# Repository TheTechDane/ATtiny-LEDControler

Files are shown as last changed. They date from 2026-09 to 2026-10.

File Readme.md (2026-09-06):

# ATtiny412 WS2812B Multi-Function LED Controller

A memory-optimized, bare-metal firmware for the **ATtiny412** microcontroller to drive up to **180 WS2812B / NeoPixel LEDs** using a single multi-function pushbutton. 

Designed for ultra-low SRAM environments (256 bytes total), the firmware utilizes **virtual tiling** and custom bit-bang streaming to repeat a 20-pixel pattern block across the full strip without running out of RAM.

All user settings (color, effect, and brightness) are bit-packed into a single byte and saved to EEPROM using a 10-second deferred write delay to maximize chip lifespan.

---

## Features

- **Virtual Tiling (180 LEDs on 256B RAM):** Allocates a 60-byte SRAM buffer (20 virtual pixels) and streams it 9 times continuously down the data wire without triggering a WS2812 reset latch.
- **Single Click:** Cycle through 8 preset colors (*Red, Yellow, Green, Cyan, Blue, Magenta, White, Warm White*).
- **Double Click:** Cycle through 8 animation modes:
  0. **Solid Color**
  1. **20-Pixel Chase**
  2. **10-Pixel Spaced Chase**
  3. **Breathing Pulse**
  4. **Alternating Blink**
  5. **Full Strip Blink**
  6. **Rainbow Spectrum Shift**
  7. **Smooth White Sparkle Fade** (Fades random LEDs smoothly to pure White at master strip brightness)
- **Long Press:** Smoothly ramps brightness in 5% steps (1% to 100%, alternating direction). Default startup brightness set to **50%** for power safety.
- **Smart EEPROM Save:** Bit-packs color, effect, and brightness into **1 byte** and commits after 10 seconds of button inactivity to prevent EEPROM wear.

***Optional***
- **Status LED:** Visual feedback for button presses on Pin 4 (`PA1`).
- **Serial Debugging:** Transmits telemetry at 115200 baud on Pin 2 (`PA6`) via `#define ENABLE_SERIAL`.

---

## Circuit Schematic & Connections

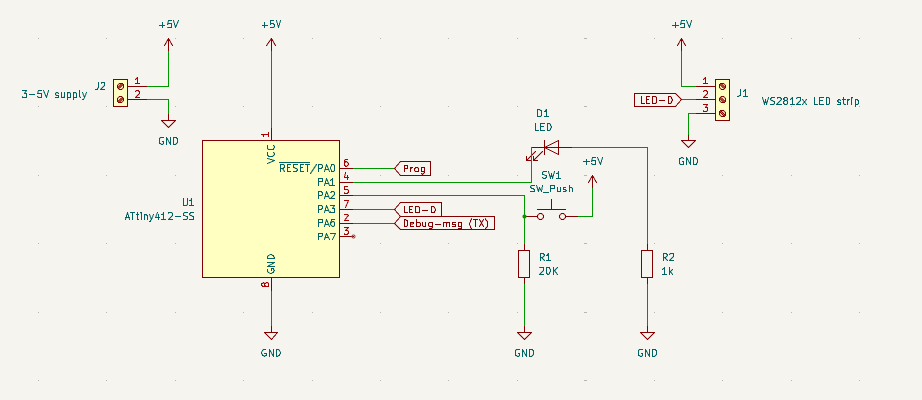
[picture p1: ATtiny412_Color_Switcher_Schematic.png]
ATtiny412 Schematic Diagram


### Hardware Pinout

| Physical Pin | AVR Pin | Function | Wiring Details |
| :---: | :---: | :--- | :--- |
| **1** | `VCC` | Power Supply | Connected to **+5V DC Power Rail** |
| **2** | `PA6` | (Serial TX) | ***Optional*** Debug output to USB-Serial Adapter RX |
| **3** | `PA7` | Unused | *Unconnected* |
| **4** | `PA1` | (Status LED) | ***Optional*** Anode (+) to Pin 4, Cathode (-) via 1kΩ Resistor to GND |
| **5** | `PA2` | Pushbutton | Button Pin 1 to **+5V**; Button Pin 2 to Pin 5 & **20kΩ Pull-down Resistor** to GND |
| **6** | `PA0` | UPDI | UPDI Programming Header |
| **7** | `PA3` | WS2812B Data | Connected directly to `DIN` on LED strip |
| **8** | `GND` | Ground | Connected to **Common Ground Rail (GND)** |

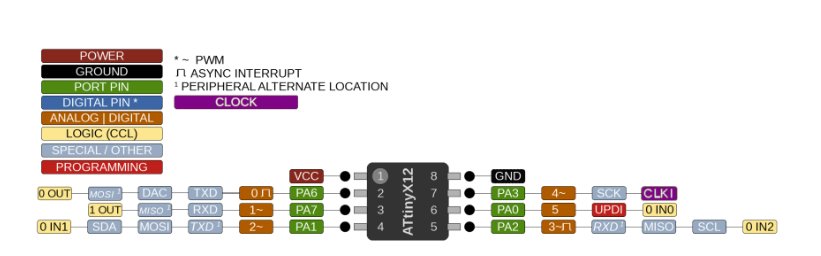
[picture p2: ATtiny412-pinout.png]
ATtiny412 Pinout


---

## Hardware Requirements

1. **ATtiny412** Microcontroller (SOIC-8 package)
2. **WS2812B LED Strip** (Up to 180 LEDs, powered by external +5V DC)
3. **1× Momentary Pushbutton**
4. **1× 20kΩ Resistor** (External pull-down for button)

***Optional***

5. **1× 1kΩ Resistor** (Current limiting for Status LED)
6. **1× Standard LED** (Status indicator)

---

## Build & Flash Instructions

1. Open `attiny412_LEDStrip_Ctrl.ino` in the **Arduino IDE**.
2. Install **megaTinyCore** via the Arduino Board Manager.
3. Configure target board settings:
   - **Board:** ATtiny412 / 402 / 212 / 202
   - **Clock:** 16 MHz or 20 MHz internal

***Optional***

4. **Upload Firmware:** Upload the compiled binary using a **SerialUPDI** or **jtag2updi** programmer connected to Pin 6 (`PA0`).
5. **Enable/Disable Serial Debugging:** Line 23 of the sketch contains `#define ENABLE_SERIAL`. Keep this line active to stream telemetry at 115200 baud on Pin 2 (`PA6`). Comment it out (`// #define ENABLE_SERIAL`) to disable debug output, save Flash memory, and reduce execution overhead.

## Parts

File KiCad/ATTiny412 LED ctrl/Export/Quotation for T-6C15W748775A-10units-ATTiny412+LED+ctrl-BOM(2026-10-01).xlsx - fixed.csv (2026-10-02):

PCBWay Bom Quotation, Product No.:T-6C15W748775A
Item # | *Designator | *Qty | Manufacturer | *Mfg Part # | Description / Value | *Package/Footprint | Mounting Type | Your Instructions / Notes | *Unit Price(10 units) | *Total | *Delivery Time | *PCBWay Note | Customer Reply | PCBWay Update
1 | D1 | 1 | Wurth Elektronik | 151033RS03000 | LED | T-1 (3 mm)『 』LED_D3.0mm_Clear | PTH | 1『 』https://www.mouser.dk/ |  |  |  | [It's out of stock. Please recommend substitutes or you can supply this part to us.] | FIXED
2 | J1 | 1 |  | No mount | WS2812x LED strip | TerminalBlock_MaiXu_MX126-5.0-03P_1x03_P5.00mm | PTH | 1 |  |  |  | [DNP];we won't purchase or populate it
3 | J2 | 1 |  | No mount | 3-5V supply | TerminalBlock_MaiXu_MX126-5.0-02P_1x02_P5.00mm | PTH | 1 |  |  |  | [DNP];we won't purchase or populate it
4 | R1 (sw) | 1 | Royalohm | CFR0W8J0203A20 | 20K | 3.6 mm『 』R_Axial_DIN0204_L3.6mm_D1.6mm_P7.62mm_Horizontal | PTH | 1『 』https://www.mouser.dk/ | $0,095 | $0,950 |  | The correct resistance value for the listed Part Number [CFR0W8J0824A20] is indeed [820kΩ], not [20KΩ]. | FIXED
5 | R2 (led) | 1 | Royalohm | CFR0W8J0102A20 | 1k | 3.6 mm『 』R_Axial_DIN0204_L3.6mm_D1.6mm_P7.62mm_Horizontal | PTH | 1『 』https://www.mouser.dk/ | $0,095 | $0,950
6 | SW1 | 1 | C&K Switches | PTS647SN70SMTR2N LFS | SW_Push | Gull Wing Lead『 』SW_SPST_PTS647_Sx38 | SMD | 1『 』https://www.mouser.dk/ | $0,442 | $4,420 | 7-10 Workdays
7 | U1 | 1 | Microchip | ATTINY412-SSN | ATtiny412-SS | SOIC-8『 』SOIC-8_3.9x4.9mm_P1.27mm | SMD | 1『 』https://www.mouser.dk/ | $0,773 | $7,730 | 7-10 Workdays
 |  |  |  |  |  |  |  |  | Component Cost | $14,05 | incomplete
 |  |  |  |  |  |  |  |  | Assembly Cost | $29,00
 |  |  |  |  |  |  |  |  | PCB Cost | $17,65
 |  |  |  |  |  |  |  |  | V1 Member 1% off | -$0,47
 |  |  |  |  |  |  |  |  | All Total 10 Units | $60,23

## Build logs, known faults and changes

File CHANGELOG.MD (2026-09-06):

# Changelog

All notable changes to the ATtiny412 WS2812B Multi-Function LED Controller will be documented in this file.

The format is based on [Keep a Changelog](https://keepachangelog.com/en/1.0.0/),
and this project adheres to [Semantic Versioning](https://semver.org/spec/v2.0.0.html).

---

## [1.2.0] - 2026-09-06

### 🚀 Added
- **10-Pixel Spaced Chase (Effect 2):** Added a denser dual-chase pattern running two active pixels spaced 10 LEDs apart across the 20-pixel virtual block.
- **Rainbow Spectrum Shift (Effect 6):** Integrated a compact 256-hue spectrum shift algorithm moving smoothly across virtual tiles.
- **Smooth White Sparkle Fade (Effect 7):** Re-engineered the Sparkle effect to smoothly ramp random individual LEDs to pure White at master strip brightness and fade them back down across a 1-second interval.
- **Fast PRNG (`fastRandom`):** Added a lightweight 16-bit Linear Feedback Shift Register pseudo-random number generator to replace bulky standard library `rand()` calls.

### ⚡ Optimizations & Memory Engineering
- **180-LED Bare-Metal Virtual Tiling Streamer (`sendRawBytesTiled`):** Bypassed standard library reset delays with custom PORTA bit-bang streaming. Transmits a 60-byte SRAM buffer (20 virtual pixels) 9 times continuously down the data wire without triggering mid-stream WS2812 reset pulses.
- **Power Rail Safety:** Adjusted default initial startup brightness to **50%** (`brightnessStep = 10`) to prevent current spikes and programmer brownouts during USB/UPDI testing.

### 🛠️ Fixed
- **Button Double-Click State Machine:** Overhauled `handleButton()` state tracking with decoupled click-window logic (`DBL_CLICK_MS = 280ms`), eliminating click drops during heavy animation rendering passes.
- **Strict SRAM Allocation:** Guaranteed total SRAM usage stays under 60 bytes (for LED buffers), leaving plenty of headspace in the ATtiny412's 256-byte SRAM pool.

---

## [1.1.0] - 2026-09-06

### 🚀 Added
- Expanded effect library to 5 modes (Solid, Moving Chase, Breathing Pulse, Alternating Blink, Full Blink).
- Multi-click button interaction framework (Single Click: Color, Double Click: Effect, Long Press: Brightness).

### ⚡ Optimizations
- **Smart EEPROM Save:** Bit-packed color, effect, and brightness settings into a single 8-bit byte with a 10-second deferred write delay to reduce EEPROM wear.

---

## [1.0.0] - 2026-08-20

### 🚀 Initial Release
- Basic WS2812B controller implementation for ATtiny412 microcontroller.
- Single button input with debouncing.
- Optional Serial debugging output at 115200 baud on Pin 2 (`PA6`).

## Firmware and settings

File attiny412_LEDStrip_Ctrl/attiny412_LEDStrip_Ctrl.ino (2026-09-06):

/*
 * ATtiny412 WS2812B Multi-Function Controller (Smooth White Fade Sparkle)
 * -----------------------------------------------------------------------------
 * LED CAPACITY CONSTRAINTS:
 * - RAM Limit: ATtiny412 has 256 bytes of SRAM total.
 * - Strip Size: Drives up to 180 physical LEDs.
 * - Pattern Buffer: Allocates RAM for 20 pixels (60 bytes SRAM) and streams 
 *   it 9 times continuously using low-level bit-banging.
 * 
 * INTERACTION:
 * - Single Click: Cycle Color (8 Presets including Warm White)
 * - Double Click: Cycle Effects (0: Solid, 1: 20px Chase, 2: 10px Chase, 
 *                 3: Breathe, 4: Alt Blink, 5: Full Blink, 6: Rainbow, 7: Sparkle Fade)
 * - Long Press:   Adjust Brightness (5% steps, 1% to 100%, alternating direction)
 * - EEPROM:       Bit-packed (1 byte) with 10-second deferred write delay.
 */

#include <EEPROM.h>

// =============================================================================
// COMPILER FLAGS & CONFIGURATION
// =============================================================================
#define ENABLE_SERIAL // Active Serial debugging on PA6

#define VIRTUAL_LEDS  20   // Pattern resolution in RAM (60 bytes SRAM)
#define ACTUAL_LEDS   180  // Total physical LEDs on strip (180 / 20 = 9 repeats)
#define NUM_REPEAT    (ACTUAL_LEDS / VIRTUAL_LEDS)
#define NUM_EFFECTS   8    // Total animation modes (0 to 7)

// EEPROM Config
#define EEPROM_ADDR_DATA      0
#define EEPROM_SAVE_DELAY_MS  10000 // 10-second delay after last button interaction

// Hardware Pin Definitions
#define LED_PIN       PIN_PA1  // Physical Pin 4 (Status LED)
#define BUTTON_PIN    PIN_PA2  // Physical Pin 5 (Button)
#define LEDSTRIP_PIN  PIN_PA3  // Physical Pin 7 (WS2812B Data Line - Bit 3 on PORTA)
#define DATA_BIT      3        // PA3

// Button Timing Constraints (ms)
#define DEBOUNCE_MS     40
#define DBL_CLICK_MS   280
#define LONG_PRESS_MS  500

// Memory buffer allocated strictly for 20 virtual pixels (60 bytes SRAM, GRB layout)
uint8_t pixels[VIRTUAL_LEDS * 3];

uint8_t colorIndex = 0;          // Range: 0 to 7
uint8_t currentEffect = 0;       // Range: 0 to 7
uint8_t brightnessStep = 10;     // Range: 0 to 20 (Set to 10 = 50% default brightness)
int8_t brightnessDirection = -1; // Ramps DOWN on first hold

// EEPROM Deferral State Variables
bool eepromDirty = false;
unsigned long lastSettingChangeTime = 0;

// Fast Lightweight PRNG state
uint16_t rngState = 0xACE1;

// Colors stored in FLASH (PROGMEM)
const uint8_t colors[8][3] PROGMEM = {
  {255, 0,   0  }, // Red
  {255, 255, 0  }, // Yellow
  {0,   255, 0  }, // Green
  {0,   255, 255}, // Cyan
  {0,   0,   255}, // Blue
  {255, 0,   255}, // Magenta
  {255, 255, 255}, // White
  {255, 197, 143}  // Warm White
};

// Button tracking variables
bool lastButtonState = LOW;
unsigned long buttonPressTime = 0;
unsigned long buttonReleaseTime = 0;
uint8_t clickCount = 0;
bool longPressExecuted = false;

// Effect animation states
unsigned long lastEffectUpdate = 0;
uint8_t effectStep = 0;
int8_t breatheDirection = 1;
uint8_t breatheStep = 100;
bool blinkToggleState = false;
uint8_t rainbowWheelPos = 0;

// Sparkle Fade state variables
uint8_t sparkleFadeProgress = 0;  // 0 to 100 (fade position inside cycle)
int8_t sparkleFadeDirection = 5;  // Step speed for fading in/out
uint8_t sparkleActivePixel = 0;   // Currently sparkling pixel index

// Lightweight 16-bit PRNG
uint16_t fastRandom() {
  rngState = (rngState >> 1) ^ (-(rngState & 1u) & 0xB400u);
  return rngState;
}

// -----------------------------------------------------------------------------
// HARDWARE WS2812B LOW-LEVEL BITBANG STREAMER
// -----------------------------------------------------------------------------
void sendRawBytesTiled(uint8_t *data, uint16_t length, uint8_t repeats) {
  uint8_t pinMask = (1 << DATA_BIT);
  
  noInterrupts();
  
  for (uint8_t r = 0; r < repeats; r++) {
    for (uint16_t i = 0; i < length; i++) {
      uint8_t b = data[i];
      for (int8_t bit = 7; bit >= 0; bit--) {
        if (b & (1 << bit)) {
          PORTA.OUTSET = pinMask;
          asm volatile("nop\n nop\n nop\n nop\n nop\n nop\n nop\n nop\n");
          PORTA.OUTCLR = pinMask;
          asm volatile("nop\n nop\n");
        } else {
          PORTA.OUTSET = pinMask;
          asm volatile("nop\n nop\n");
          PORTA.OUTCLR = pinMask;
          asm volatile("nop\n nop\n nop\n nop\n nop\n nop\n nop\n nop\n");
        }
      }
    }
  }
  
  interrupts();
  delayMicroseconds(60); // Force WS2812 Reset pulse
}

void setPixelGRB(uint8_t index, uint8_t r, uint8_t g, uint8_t b) {
  if (index >= VIRTUAL_LEDS) return;
  pixels[index * 3 + 0] = g; // Green
  pixels[index * 3 + 1] = r; // Red
  pixels[index * 3 + 2] = b; // Blue
}

// Compact Hue-to-RGB conversion
void getRainbowColor(uint8_t pos, uint8_t *r, uint8_t *g, uint8_t *b) {
  pos = 255 - pos;
  if (pos < 85) {
    *r = 255 - pos * 3; *g = 0; *b = pos * 3;
  } else if (pos < 170) {
    pos -= 85;
    *r = 0; *g = pos * 3; *b = 255 - pos * 3;
  } else {
    pos -= 170;
    *r = pos * 3; *g = 255 - pos * 3; *b = 0;
  }
}

// -----------------------------------------------------------------------------
// BIT-PACKING & EEPROM HELPERS
// -----------------------------------------------------------------------------
uint8_t packSettings() {
  uint8_t bScale = brightnessStep / 6; // Map 0-20 down to 0-3 (2 bits)
  return (colorIndex & 0x07) | ((currentEffect & 0x07) << 3) | ((bScale & 0x03) << 6);
}

void unpackSettings(uint8_t packedVal) {
  colorIndex = packedVal & 0x07;
  currentEffect = (packedVal >> 3) & 0x07;
  brightnessStep = ((packedVal >> 6) & 0x03) * 6;
  if (brightnessStep > 20) brightnessStep = 20;
}

void markSettingChanged() {
  eepromDirty = true;
  lastSettingChangeTime = millis();
}

void processEEPROMSave() {
  if (eepromDirty && (millis() - lastSettingChangeTime >= EEPROM_SAVE_DELAY_MS)) {
    EEPROM.update(EEPROM_ADDR_DATA, packSettings());
    eepromDirty = false;

#ifdef ENABLE_SERIAL
    Serial.println(F("Saved to EEPROM!"));
#endif
  }
}

void loadSettings() {
  uint8_t packedVal = EEPROM.read(EEPROM_ADDR_DATA);
  if (packedVal != 0xFF) {
    unpackSettings(packedVal);
    if (colorIndex >= 8) colorIndex = 0;
    if (currentEffect >= NUM_EFFECTS) currentEffect = 0;
  }
}

// -----------------------------------------------------------------------------
// LED OUTPUT CONTROLLER
// -----------------------------------------------------------------------------
void applyStripOutput() {
  uint8_t baseR = pgm_read_byte(&(colors[colorIndex][0]));
  uint8_t baseG = pgm_read_byte(&(colors[colorIndex][1]));
  uint8_t baseB = pgm_read_byte(&(colors[colorIndex][2]));

  uint8_t scaleFactor = (brightnessStep == 0) ? 3 : (uint8_t)((uint16_t)brightnessStep * 255 / 20);

  if (currentEffect == 3) { // Breathing Pulse
    scaleFactor = (scaleFactor * breatheStep) / 100;
  }

  uint8_t r = (baseR * scaleFactor) >> 8;
  uint8_t g = (baseG * scaleFactor) >> 8;
  uint8_t b = (baseB * scaleFactor) >> 8;

  // Populate 20-pixel Virtual Pattern Buffer
  for (uint8_t i = 0; i < VIRTUAL_LEDS; i++) {
    uint8_t pr = r, pg = g, pb = b;

    if (currentEffect == 1) { // 20-pixel Chase
      bool active = (i == (effectStep % VIRTUAL_LEDS));
      pr = active ? r : 0; pg = active ? g : 0; pb = active ? b : 0;
    } 
    else if (currentEffect == 2) { // 10-pixel Spaced Chase
      bool active = ((i % 10) == (effectStep % 10));
      pr = active ? r : 0; pg = active ? g : 0; pb = active ? b : 0;
    }
    else if (currentEffect >= 4 && currentEffect <= 5) { // Blink / Alt Blink
      bool active = (currentEffect == 5) ? blinkToggleState : ((i % 2 == 0) ? blinkToggleState : !blinkToggleState);
      pr = active ? r : 0; pg = active ? g : 0; pb = active ? b : 0;
    } 
    else if (currentEffect == 6) { // Rainbow Spectrum
      getRainbowColor((uint8_t)((i * 256 / VIRTUAL_LEDS) + rainbowWheelPos), &pr, &pg, &pb);
      pr = (pr * scaleFactor) >> 8;
      pg = (pg * scaleFactor) >> 8;
      pb = (pb * scaleFactor) >> 8;
    } 
    else if (currentEffect == 7) { // Smooth White Fade Sparkle
      if (i == sparkleActivePixel) {
        // Calculate cross-fade between base color and pure white based on fade progress
        uint8_t targetWhite = scaleFactor; // Matches exact current strip brightness
        pr = r + (((int16_t)targetWhite - r) * sparkleFadeProgress / 100);
        pg = g + (((int16_t)targetWhite - g) * sparkleFadeProgress / 100);
        pb = b + (((int16_t)targetWhite - b) * sparkleFadeProgress / 100);
      }
    }

    setPixelGRB(i, pr, pg, pb);
  }

  // Stream raw buffer 9 times (180 LEDs)
  sendRawBytesTiled(pixels, VIRTUAL_LEDS * 3, NUM_REPEAT);
}

// -----------------------------------------------------------------------------
// BUTTON INTERACTION HANDLERS
// -----------------------------------------------------------------------------
void onSingleClick() {
  digitalWrite(LED_PIN, HIGH);
  colorIndex = (colorIndex + 1) % 8;
  markSettingChanged();
  applyStripOutput();

#ifdef ENABLE_SERIAL
  Serial.print(F("Color: "));
  Serial.println(colorIndex);
#endif

  delay(20);
  digitalWrite(LED_PIN, LOW);
}

void onDoubleClick() {
  digitalWrite(LED_PIN, HIGH);
  currentEffect = (currentEffect + 1) % NUM_EFFECTS;
  markSettingChanged();
  applyStripOutput();

#ifdef ENABLE_SERIAL
  Serial.print(F("Effect: "));
  Serial.println(currentEffect);
#endif

  delay(100);
  digitalWrite(LED_PIN, LOW);
}

void onLongPressHold() {
  digitalWrite(LED_PIN, HIGH);

  int8_t nextStep = brightnessStep + brightnessDirection;

  if (nextStep >= 20) brightnessStep = 20;
  else if (nextStep <= 0) brightnessStep = 0;
  else brightnessStep = nextStep;

  applyStripOutput();

#ifdef ENABLE_SERIAL
  Serial.print(F("Bright: "));
  Serial.print(brightnessStep == 0 ? 1 : brightnessStep * 5);
  Serial.println(F("%"));
#endif

  delay(30);
  digitalWrite(LED_PIN, LOW);
}

void handleButton() {
  bool currentButtonState = digitalRead(BUTTON_PIN);
  unsigned long now = millis();

  if (currentButtonState == HIGH && lastButtonState == LOW) {
    buttonPressTime = now;
    longPressExecuted = false;
  }

  if (currentButtonState == HIGH && (now - buttonPressTime >= LONG_PRESS_MS)) {
    clickCount = 0;
    onLongPressHold();
    delay(80); 
    longPressExecuted = true;
  }

  if (currentButtonState == LOW && lastButtonState == HIGH) {
    buttonReleaseTime = now;

    if (longPressExecuted) {
      markSettingChanged();
      brightnessDirection = -brightnessDirection;
    } else if (now - buttonPressTime >= DEBOUNCE_MS) {
      clickCount++;
    }
  }

  if (clickCount > 0 && (now - buttonReleaseTime > DBL_CLICK_MS) && currentButtonState == LOW) {
    if (clickCount == 1) {
      onSingleClick();
    } else if (clickCount >= 2) {
      onDoubleClick();
    }
    clickCount = 0;
  }

  lastButtonState = currentButtonState;
}

// -----------------------------------------------------------------------------
// SETUP & MAIN LOOP
// -----------------------------------------------------------------------------
void setup() {
#ifdef ENABLE_SERIAL
  Serial.begin(115200, SERIAL_8N1 | SERIAL_TX_ONLY);
  Serial.println(F("Ready"));
#endif

  pinMode(LED_PIN, OUTPUT);
  pinMode(LEDSTRIP_PIN, OUTPUT);
  pinMode(BUTTON_PIN, INPUT);

  loadSettings();

  applyStripOutput();
}

void loop() {
  handleButton();
  processEEPROMSave();

  if (currentEffect > 0) {
    unsigned long now = millis();
    uint16_t interval = 80;

    if (currentEffect == 1 || currentEffect == 2) interval = 80;
    else if (currentEffect == 3) interval = 25;
    else if (currentEffect == 4) interval = 300;
    else if (currentEffect == 5) interval = 250;
    else if (currentEffect == 6) interval = 30; // Rainbow speed
    else if (currentEffect == 7) interval = 25; // Smooth 25ms step update for Sparkle Fade

    if (now - lastEffectUpdate > interval) {
      lastEffectUpdate = now;

      if (currentEffect == 1 || currentEffect == 2) {
        effectStep = (effectStep + 1) % VIRTUAL_LEDS;
      } else if (currentEffect == 3) {
        if (breatheStep >= 100) breatheDirection = -2;
        if (breatheStep <= 10) breatheDirection = 2;
        breatheStep += breatheDirection;
      } else if (currentEffect >= 4 && currentEffect <= 5) {
        blinkToggleState = !blinkToggleState;
      } else if (currentEffect == 6) {
        rainbowWheelPos += 4;
      } else if (currentEffect == 7) {
        // Smoothly ramp sparkle white level up to 100% and back down to 0%
        if (sparkleFadeDirection > 0) {
          if (sparkleFadeProgress >= 100) {
            sparkleFadeDirection = -5; // Peak reached, fade out
          } else {
            sparkleFadeProgress += sparkleFadeDirection;
          }
        } else {
          if (sparkleFadeProgress <= 0) {
            // Fade out finished, select a new random LED pixel to sparkle next
            sparkleActivePixel = fastRandom() % VIRTUAL_LEDS;
            sparkleFadeDirection = 5; // Start fading in new pixel
          } else {
            sparkleFadeProgress += sparkleFadeDirection;
          }
        }
      }

      applyStripOutput();
    }
  }
}

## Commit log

2026-09-06 First version of the LEDStrip controller .
    Just with in the 4k limit with debugging and all the initial ideas: Features:
    - Single Click: Cycle Color
    - Double Click: Cycle Effects (0: Solid, 1: Chase, 2: Breathe, 3: Alt Blink, 4: Full Blink)
    - Long Press: Adjust Brightness (21 steps: 1% - 100%)
    EEPROM Management:
    - Bit-Packing: Compresses Color (3 bits), Effect (3 bits), and Brightness (2 bits/scaled)
    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
2026-09-06 Ver 1.2 Update
    feat(effects): add smooth white sparkle fade & 10px chase; fix 180-LED tiling
    - Implement low-level bit-bang streamer for 20-pixel tile repeated across 180 LEDs without WS2812 reset latches.
    - Expand effect library to 8 modes (Solid, 20px Chase, 10px Chase, Breathe, Alt Blink, Full Blink, Rainbow, Sparkle Fade).
    - Refructure Sparkle effect to smoothly fade pure white highlights in/out matching strip brightness.
    - Fix button timing state machine for reliable double-click detection during dynamic renders.
    - Default startup brightness set to 50% for power rail safety.
    [attiny412_LEDStrip_Ctrl.ino]
2026-09-26 V1 PCB
    [ATTiny412 LED ctrl - BOM-us.csv, ATTiny412 LED ctrl - BOM.csv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]
2026-09-27 V1.1 PCB
    [ATTiny412 LED ctrl - BOM-us.csv, ATTiny412 LED ctrl-BOM.csv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]
2026-09-28 Mfr. No added
    [ATTiny412 LED ctrl-BOM.csv]
2026-09-30 More details on the 1.1 BOM
    [ATTiny412 LED ctrl-BOM.csv]
2026-09-30 New BOM In export as well
    [ATTiny412 LED ctrl-BOM.csv]
2026-10-02 Modified file for v1.1 with fixed requested problems
    [Quotation for T-6C15W748775A-10units-ATTiny412+LED+ctrl-BOM(2026-10-01).xlsx - fixed.csv]
2026-10-12 V. 2.0 - Lava Scene added, Active low Button
2026-10-12 KiCad changes
2026-10-14 Kicad update for JCBPCB v2.0 with placement
2026-10-14 Doc update for HW / SW v2.1.
    Button Active Low, Mis config on LED, Doc updated
2026-10-14 Update ATtiny412 Schematic Diagram.png
2026-10-15 JLCPCB updated version 2.1
    LED was reversed now fixed
2026-10-15 Update components list in Readme.md
    Removed the 20kΩ resistor from the required components list.
2026-10-17 First version of the #D Printed box
    Box with 6 different options of Lits
